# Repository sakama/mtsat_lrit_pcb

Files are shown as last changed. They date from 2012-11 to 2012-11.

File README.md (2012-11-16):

# MTSAT LRIT PCB

#What's this?#

----------
MTSATのLRIT信号を受信するためのダウンコンバータ及びデコーダの回路図。Eagleで作成。

[Maker Faire Tokyo 2012](http://makezine.jp/)に出品予定。

こちらの記事に書いてあるものを基板に起こしたもの
[http://www.wa.commufa.jp/gigast/SAT/LRIT/LRIT.html](http://www.wa.commufa.jp/gigast/SAT/LRIT/LRIT.html)

# How to use #

----------

Please download CadSoft [EAGLE PCB](http://www.cadsoftusa.com/)

# About MTSAT LRIT #

http://www.jma.go.jp/jma/jma-eng/satellite/mtsat1r/4.3LRIT.pdf

## License ##

----------

Non-Commecial Use Only

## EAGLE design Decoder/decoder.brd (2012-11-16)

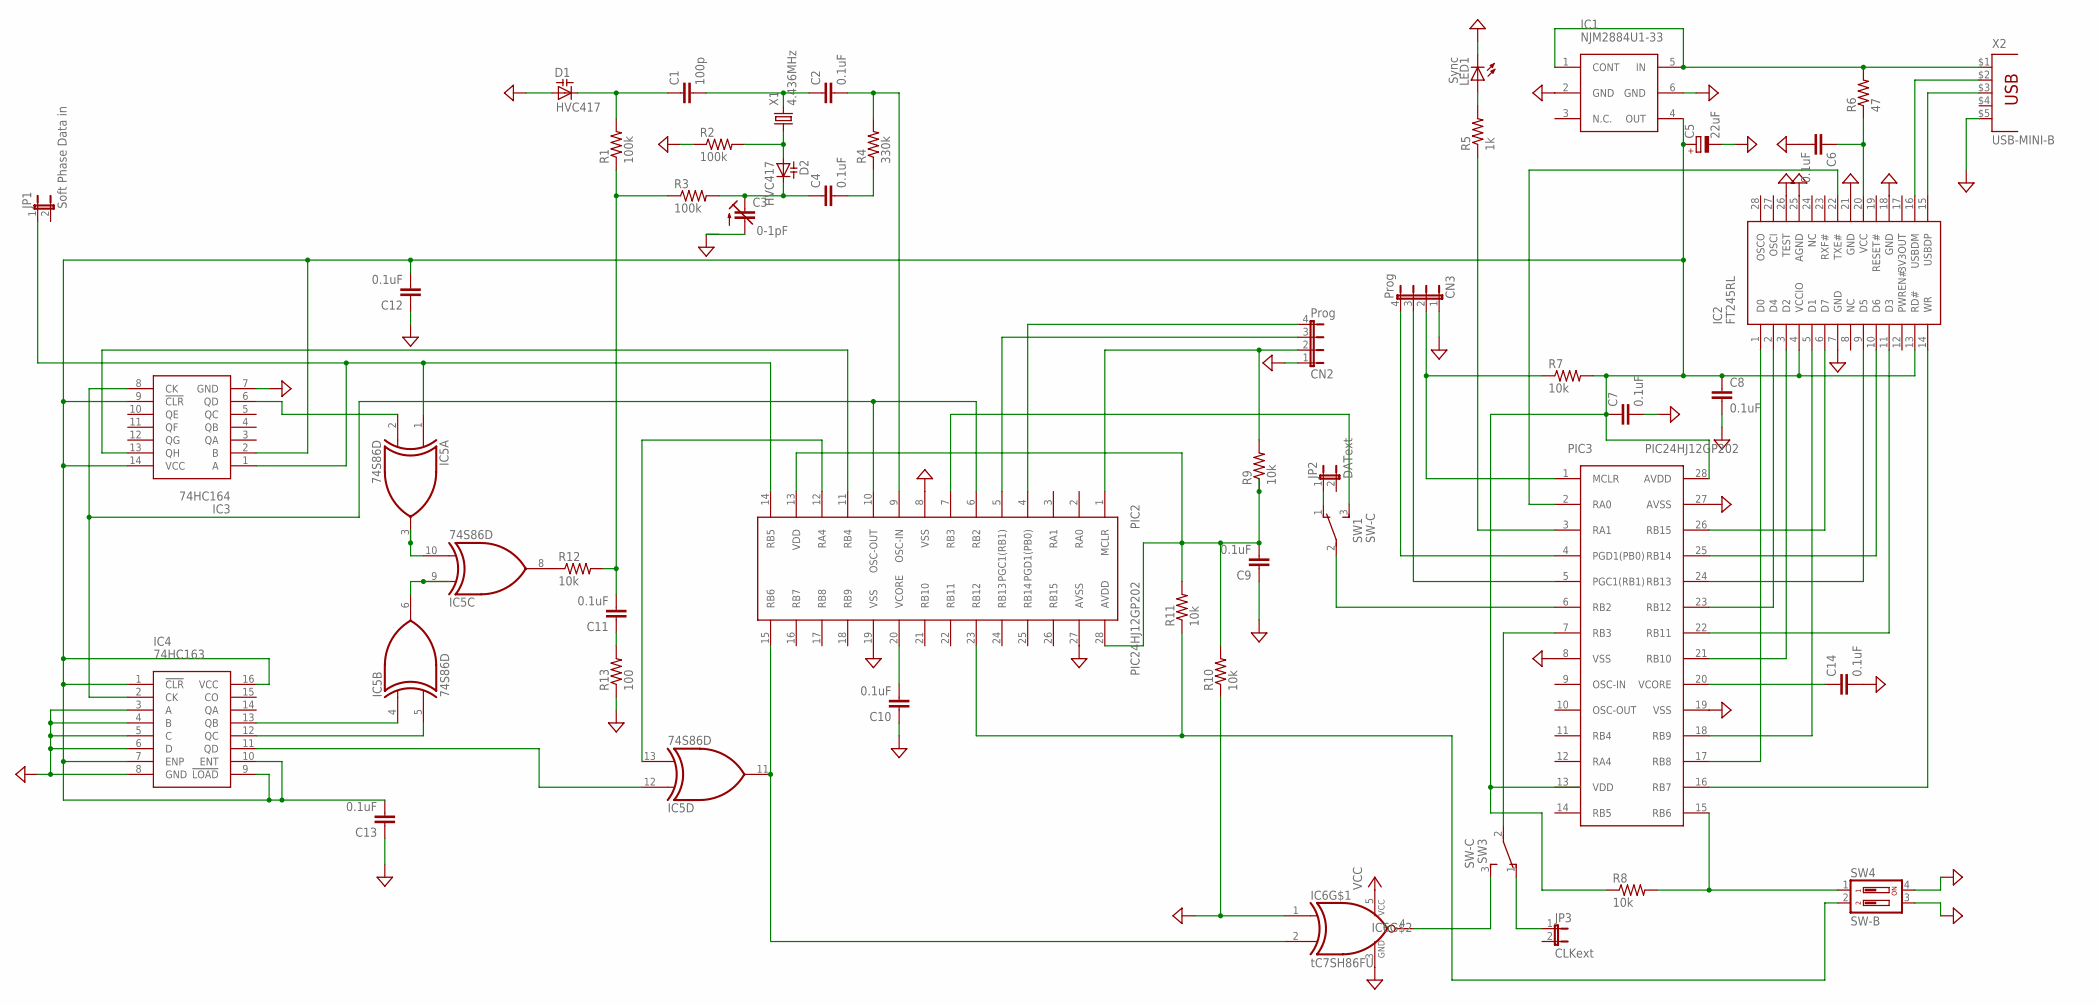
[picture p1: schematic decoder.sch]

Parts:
C1: 100p; C025-025X050
C2, C4, C6, C7, C8, C9, C10, C11, C12, C13, C14: 0.1uF; C050-025X075
C3: 0-1pF; CTRIMTZ03
C5: 22uF; E3,5-8
CN2, CN3: Prog; JP4
D1, D2: HVC417; SOT54H
IC1: NJM2884U1-33
IC2: FT245RL
IC3: 74HC164
IC4: 74HC163
IC5: 74S86D; SO14
IC6: tC7SH86FU; TC7SH86FU
JP1: Soft Phase Data in; JP1
JP2: DAText; JP1
JP3: CLKext; JP1
LED1: Sync; LED5MM
PIC2, PIC3: PIC24HJ12GP202
R1, R2, R3: 100k; 0207/7
R4: 330k; 0207/7
R5: 1k; 0207/7
R6: 47; 0207/7
R7, R8, R9, R10, R11, R12: 10k; 0207/7
R13: 100; 0207/7
SW1, SW3: SW-C; TL3XPO
SW4: SW-B; DIP02YL
X1: 4.436MHz; HC49/S
X2: USB-MINI-B

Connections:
GND: C3.2 (A), C5.-, C6.2, C7.2, C8.2, C9.1, C10.1, C12.1, C13.1, C14.2, CN2.1, CN3.1, D1.A, IC1.2 (GND), IC1.6 (GND), IC2.7 (GND), IC2.18 (GND), IC2.21 (GND), IC2.25 (AGND), IC2.26 (TEST), IC3.7 (GND), IC4.3 (A), IC4.4 (B), IC4.5 (C), IC4.6 (D), IC4.8 (GND), IC5.7 (GND), IC6.1 (I0), IC6.3 (GND), LED1.K (C), PIC2.8 (VSS), PIC2.19 (VSS), PIC2.27 (AVSS), PIC3.8 (VSS), PIC3.19 (VSS), PIC3.27 (AVSS), R2.1, R10.1, R13.1, SW4.3, SW4.4, X2.$5 (5)
unnamed: IC1.1 (CONT), IC1.5 (IN), R6.2, X2.$1 (1)
unnamed: C4.2, R4.1
unnamed: C1.2, C2.1, X1.2
unnamed: C2.2, PIC2.9 (OSC-IN), R4.2
unnamed: CN2.2, PIC2.1 (MCLR), R9.2
unnamed: C3.1 (E), C4.1, D2.C, R3.2
unnamed: C1.1, D1.C, R1.2
unnamed: IC5.8 (O), R12.1
unnamed: C10.2, PIC2.20 (VCORE)
unnamed: PIC2.23 (RB12), R11.1, SW4.2
unnamed: PIC3.15 (RB6), R8.2, SW4.1
unnamed: C11.1, R13.2
unnamed: PIC2.7 (RB3), SW1.3 (S)
unnamed: PIC3.6 (RB2), SW1.2
unnamed: IC5.11 (O), IC6.2 (I1), PIC2.15 (RB6)
unnamed: PIC3.3 (RA1), R5.1
unnamed: PIC3.7 (RB3), SW3.2
unnamed: C9.2, PIC2.13 (VDD), PIC2.28 (AVDD), R9.1, R10.2, R11.2
unnamed: IC2.22 (TXE#), PIC3.2 (RA0)
unnamed: C11.2, R1.1, R3.1, R12.2
unnamed: IC5.6 (O), IC5.9 (I0)
unnamed: IC5.3 (O), IC5.10 (I1)
unnamed: IC3.1 (A), IC5.1 (I0), JP1.1, PIC2.14 (RB5)
unnamed: IC5.13 (I1), PIC2.12 (RA4)
unnamed: IC2.14 (WR), PIC3.16 (RB7)
unnamed: D2.A, R2.2, X1.1
unnamed: IC2.10 (D6), PIC3.25 (RB14)
unnamed: IC2.15 (USBDP), X2.$3 (3)
unnamed: IC2.16 (USBDM), X2.$2 (2)
unnamed: IC2.11 (D3), PIC3.22 (RB11)
unnamed: IC2.9 (D5), PIC3.24 (RB13)
unnamed: IC2.1 (D0), PIC3.17 (RB8)
unnamed: IC2.2 (D4), PIC3.23 (RB12)
unnamed: IC2.3 (D2), PIC3.21 (RB10)
unnamed: IC2.5 (D1), PIC3.18 (RB9)
unnamed: IC2.6 (D7), PIC3.26 (RB15)
unnamed: IC3.6 (QD), IC5.2 (I1)
unnamed: IC3.13 (QH), PIC2.11 (RB4)
unnamed: IC4.13 (QB), IC5.4 (I0)
unnamed: IC4.12 (QC), IC5.5 (I1)
unnamed: IC4.11 (QD), IC5.12 (I0)
unnamed: JP3.1, SW3.1 (O)
unnamed: C5.+, C7.1, C8.1, C12.2, C13.2, IC1.4 (OUT), IC2.4 (VCCIO), IC2.13 (RD#), IC3.2 (B), IC3.9 (!CLR), IC3.14 (VCC), IC4.1 (!CLR), IC4.7 (ENP), IC4.9 (!LOAD), IC4.10 (ENT), IC4.16 (VCC), PIC3.28 (AVDD), R7.2, R8.1
unnamed: IC3.8 (CK), IC4.2 (CK), PIC2.6 (RB2), PIC2.10 (OSC-OUT)
unnamed: C6.1, IC2.20 (VCC), R6.1
unnamed: CN2.3, PIC2.5 (PGC1(RB1))
unnamed: CN2.4, PIC2.4 (PGD1(PB0))
unnamed: CN3.2, PIC3.1 (MCLR), R7.1
unnamed: CN3.3, PIC3.5 (PGC1(RB1))
unnamed: CN3.4, PIC3.4 (PGD1(PB0))
unnamed: LED1.A, R5.2
unnamed: JP2.1, SW1.1 (O)
unnamed: IC6.4 (O), SW3.3 (S)
unnamed: C14.1, PIC3.20 (VCORE)
VCC: IC5.14 (VCC), IC6.5 (VCC)
VDD: PIC3.13 (VDD)

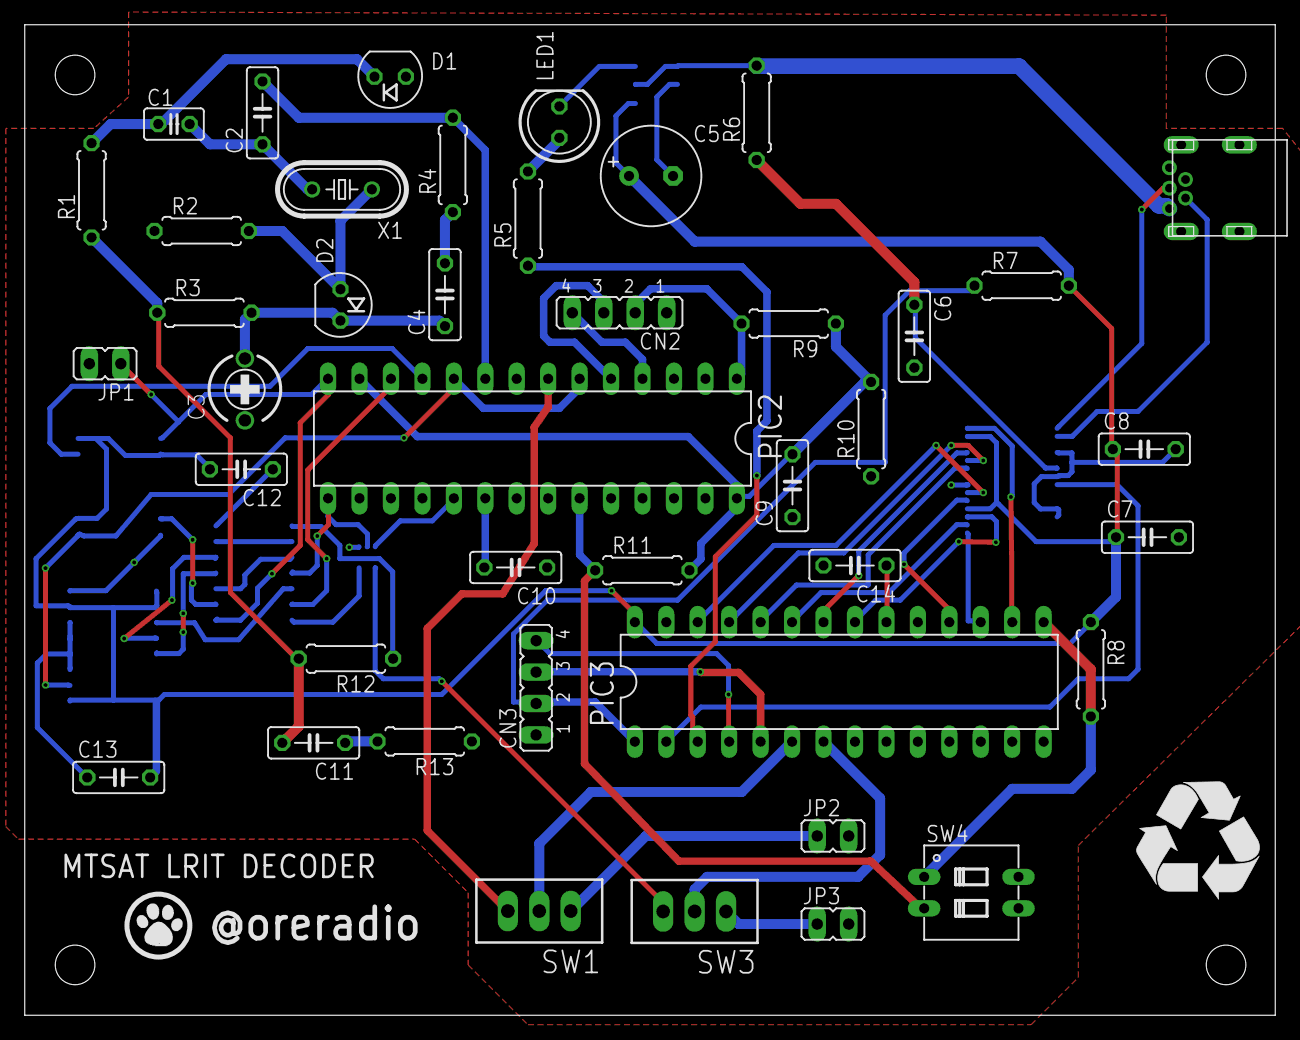
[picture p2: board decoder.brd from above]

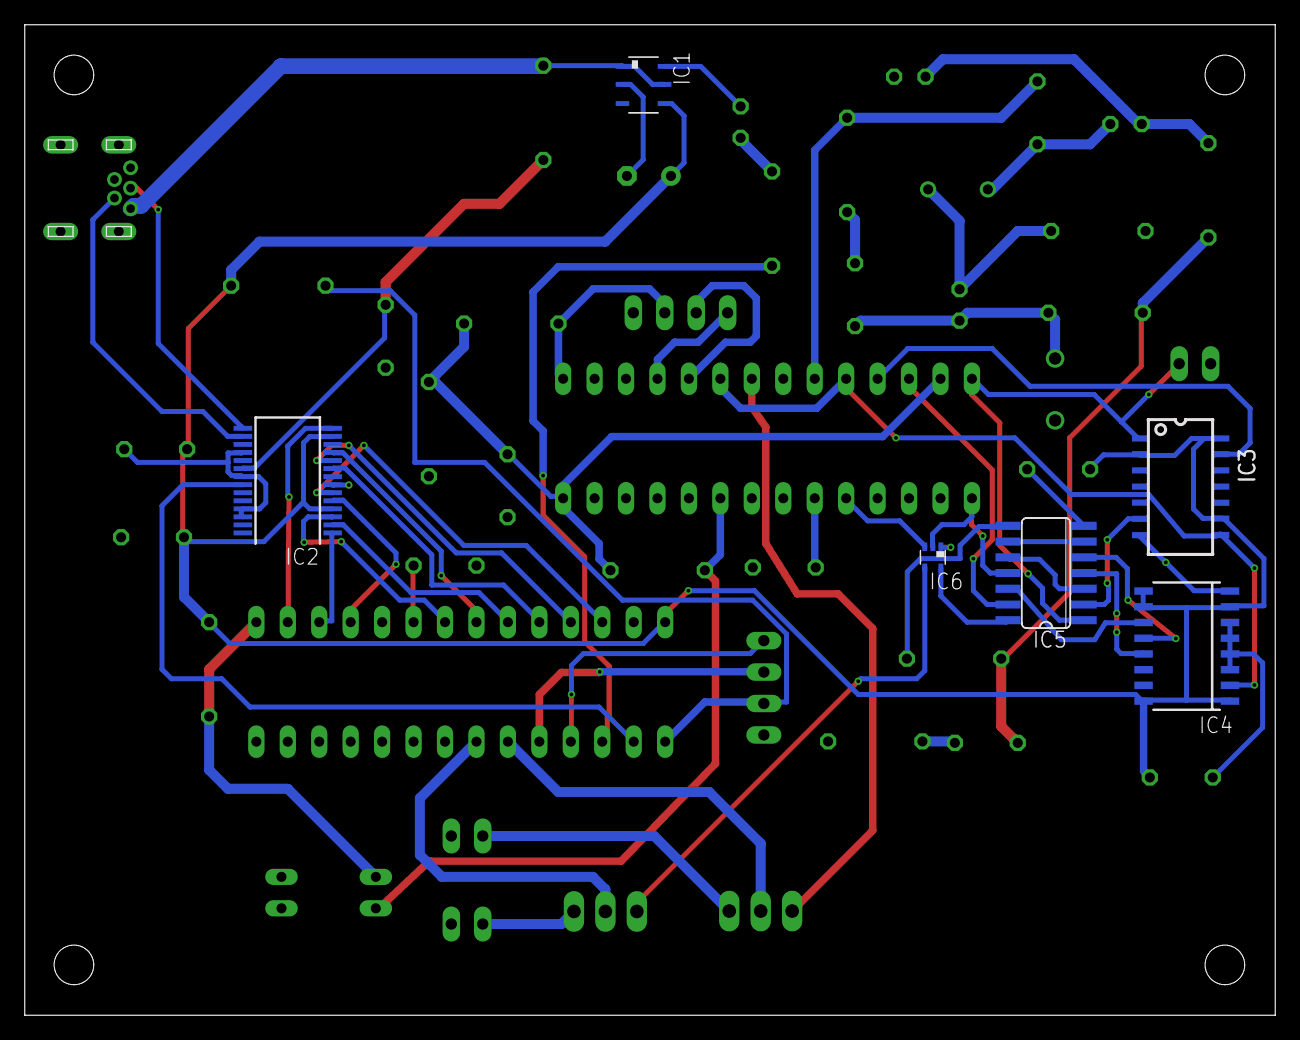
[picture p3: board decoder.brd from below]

Board: 2 copper layers, 101.0 x 80.0 mm, 50 parts (6 on the bottom side), 56 nets.

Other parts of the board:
U$36: LOGO
U$38: RECYCLING_10.00

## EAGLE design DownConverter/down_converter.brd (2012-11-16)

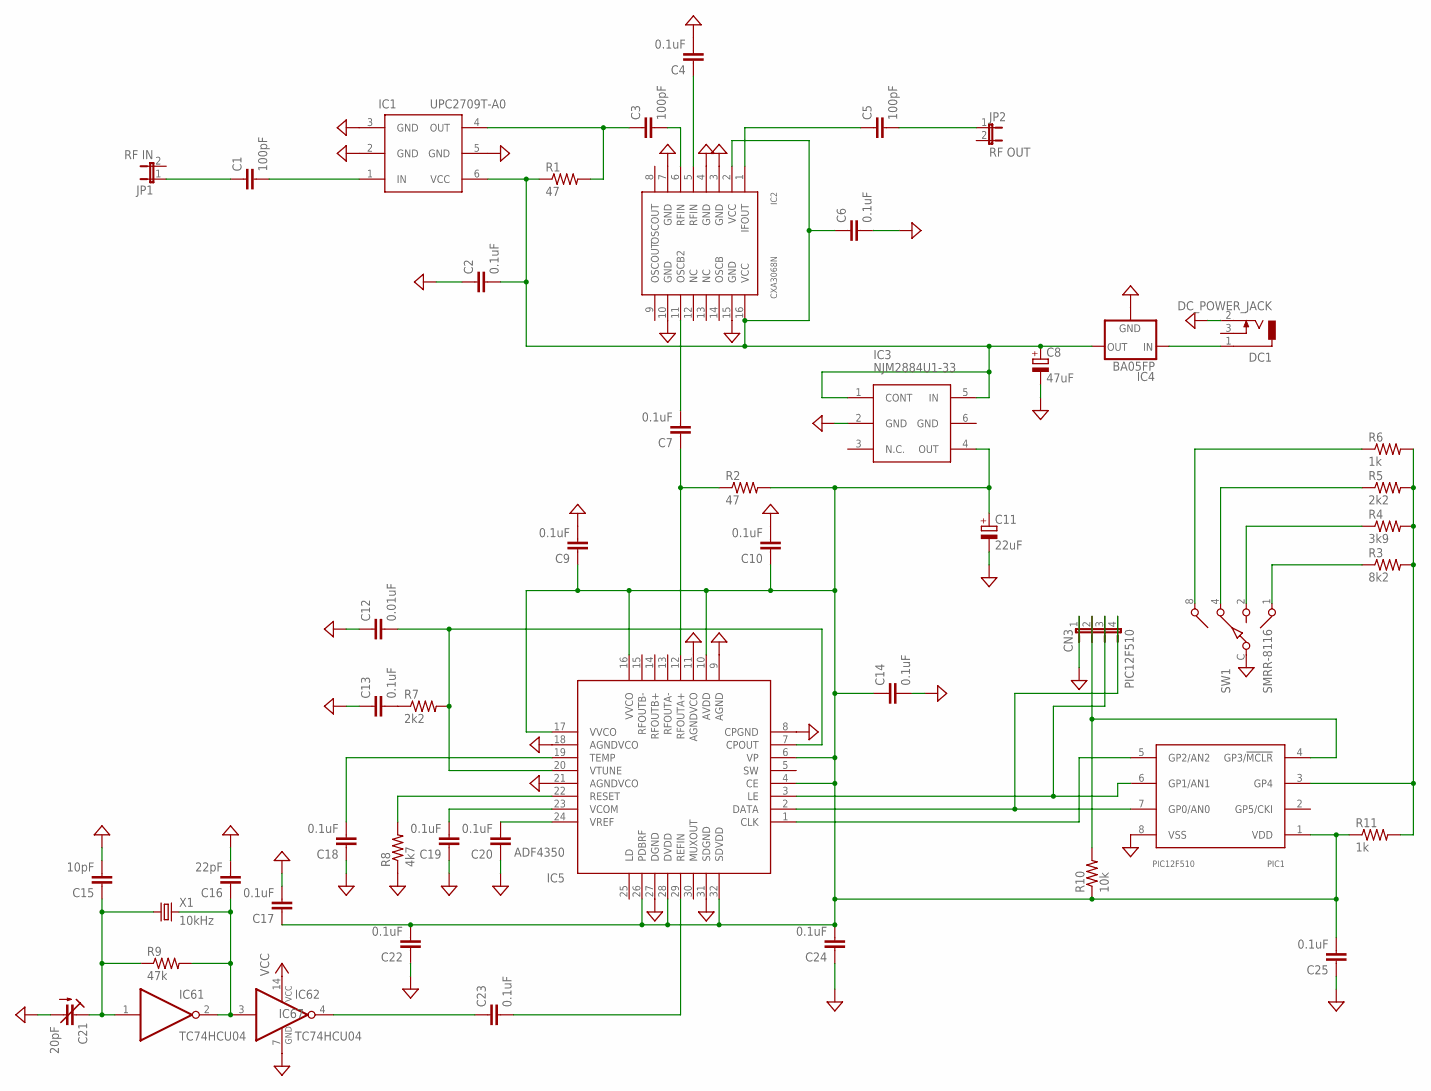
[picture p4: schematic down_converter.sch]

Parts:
C1, C3, C5: 100pF; C025-025X050
C2, C4, C6, C7, C9, C10, C13, C14, C17, C18, C19, C20, C22, C23, C24, C25: 0.1uF; C050-025X075
C8: 47uF; E5-10,5
C11: 22uF; E3,5-8
C12: 0.01uF; C025-025X050
C15: 10pF; C025-025X050
C16: 22pF; C025-025X050
C21: 20pF; CTRIMTZ03
CN3: PIC12F510; JP4
DC1: DC_POWER_JACK
IC1: UPC2709T-A0; SOT23-6
IC2: CXA3068N
IC3: NJM2884U1-33
IC4: BA05FP
IC5: ADF4350
IC6: TC74HCU04
JP1: RF IN; JP1
JP2: RF OUT; JP1
PIC1: PIC12F510; PIC12F1288
R1, R2: 47; 0207/7
R3: 8k2; 0207/7
R4: 3k9; 0207/7
R5, R7: 2k2; 0207/7
R6, R11: 1k; 0207/7
R8: 4k7; 0207/7
R9: 47k; 0207/7
R10: 10k; 0207/7
SW1: SMRR-8116; SW-C16
X1: 10kHz; HC49/S

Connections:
GND: C2.1, C4.2, C6.2, C8.-, C9.2, C10.2, C11.-, C12.1, C13.1, C14.2, C15.2, C16.2, C17.2, C18.1, C19.1, C20.1, C21.2 (A), C22.1, C24.1, C25.1, CN3.1, DC1.2, IC1.2 (GND), IC1.3 (GND), IC1.5 (GND), IC2.3 (GND), IC2.4 (GND), IC2.7 (GND), IC2.10 (GND), IC2.15 (GND), IC3.2 (GND), IC3.6 (GND), IC4.2 (GND), IC5.8 (CPGND), IC5.9 (AGND), IC5.11 (AGNDVCO), IC5.18 (AGNDVCO), IC5.21 (AGNDVCO), IC5.27 (DGND), IC5.31 (SDGND), IC6.7 (GND), PIC1.8 (VSS), R8.1, SW1.C
unnamed: C13.2, R7.1
unnamed: DC1.1, IC4.1 (IN)
unnamed: C23.2, IC5.29 (REFIN)
unnamed: C20.2, IC5.24 (VREF)
unnamed: C19.2, IC5.23 (VCOM)
unnamed: IC5.22 (RESET), R8.2
unnamed: C18.2, IC5.19 (TEMP)
unnamed: C12.2, IC5.7 (CPOUT), IC5.20 (VTUNE), R7.2
unnamed: C7.1, IC5.12 (RFOUTA+), R2.1
unnamed: C2.2, C6.1, C8.+, IC1.6 (VCC), IC2.2 (VCC), IC2.16 (VCC), IC3.1 (CONT), IC3.5 (IN), IC4.3 (OUT), R1.1
unnamed: IC5.1 (CLK), PIC1.5 (GP2/AN2)
unnamed: PIC1.3 (GP4), R3.2, R4.2, R5.2, R6.2, R11.2
unnamed: C7.2, IC2.11 (OSCB2)
unnamed: C3.1, IC1.4 (OUT), R1.2
unnamed: C1.2, IC1.1 (IN)
unnamed: C3.2, IC2.6 (RFIN)
unnamed: C4.1, IC2.5 (RFIN)
unnamed: C5.1, IC2.1 (IFOUT)
unnamed: R6.1, SW1.8
unnamed: CN3.2, PIC1.4 (GP3/!MCLR), R10.2
unnamed: R5.1, SW1.4
unnamed: R4.1, SW1.2
unnamed: R3.1, SW1.1
unnamed: CN3.3, IC5.3 (LE), PIC1.6 (GP1/AN1)
unnamed: C5.2, JP2.1
unnamed: C1.1, JP1.1
unnamed: C9.1, C10.1, C11.+, C14.1, C17.1, C22.2, C24.2, C25.2, IC3.4 (OUT), IC5.4 (CE), IC5.6 (VP), IC5.10 (AVDD), IC5.16 (VVCO), IC5.17 (VVCO), IC5.26 (PDBRF), IC5.28 (DVDD), IC5.32 (SDVDD), PIC1.1 (VDD), R2.2, R10.1, R11.1
unnamed: C16.1, IC6.2 (Y), IC6.3 (A), R9.2, X1.2
unnamed: C15.1, C21.1 (E), IC6.1 (A), R9.1, X1.1
unnamed: C23.1, IC6.4 (Y)
unnamed: CN3.4, IC5.2 (DATA), PIC1.7 (GP0/AN0)
VCC: IC6.14 (VCC)

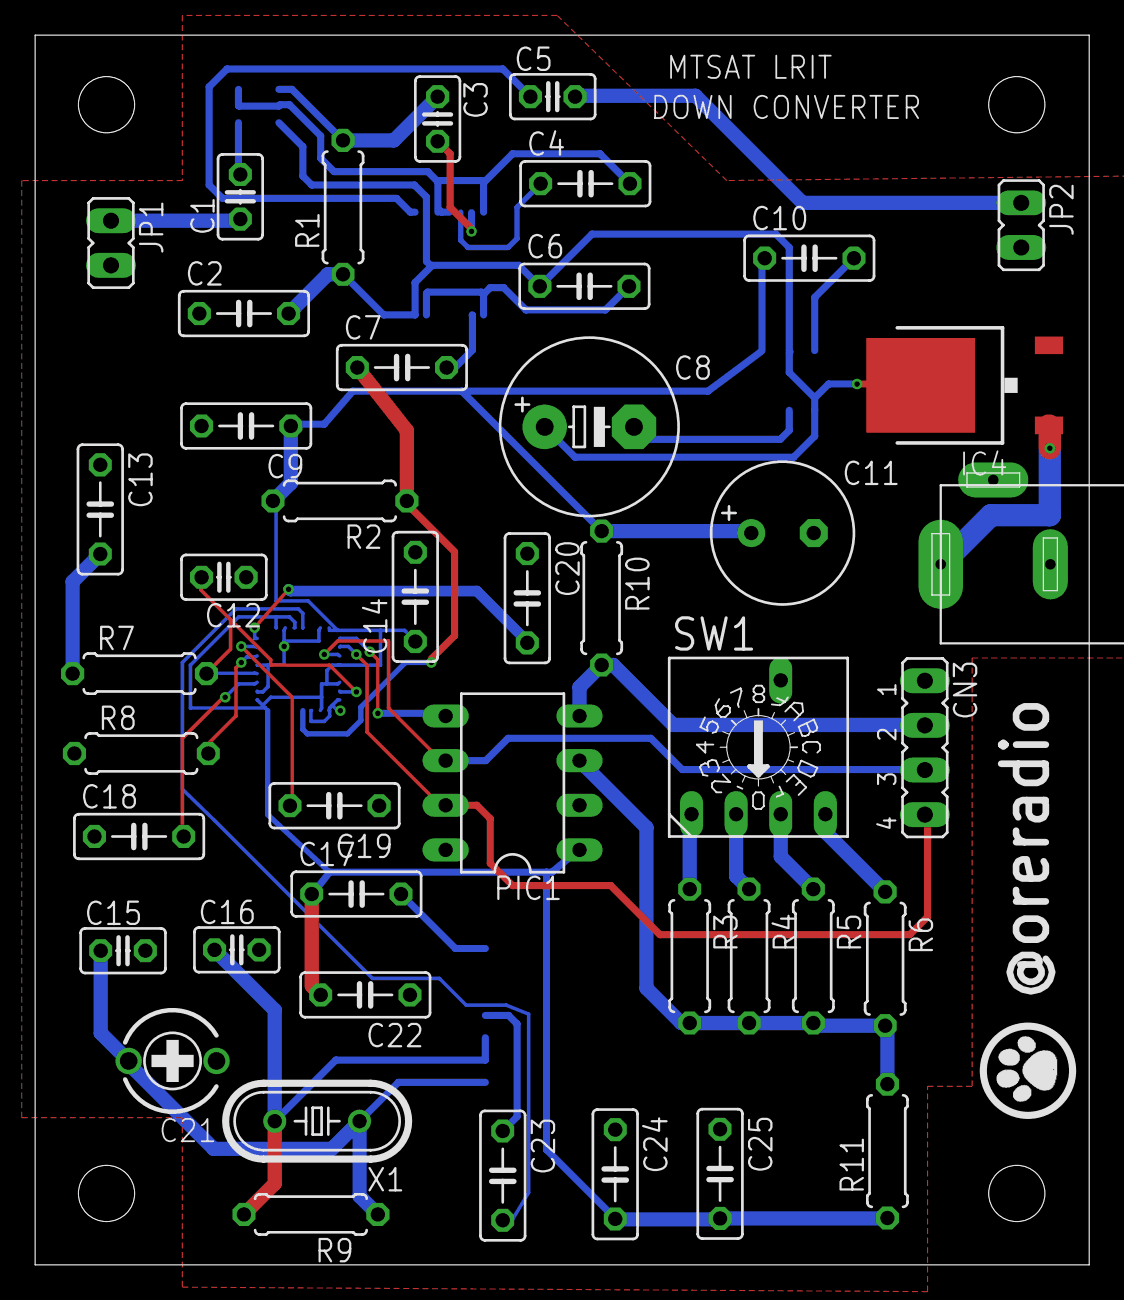
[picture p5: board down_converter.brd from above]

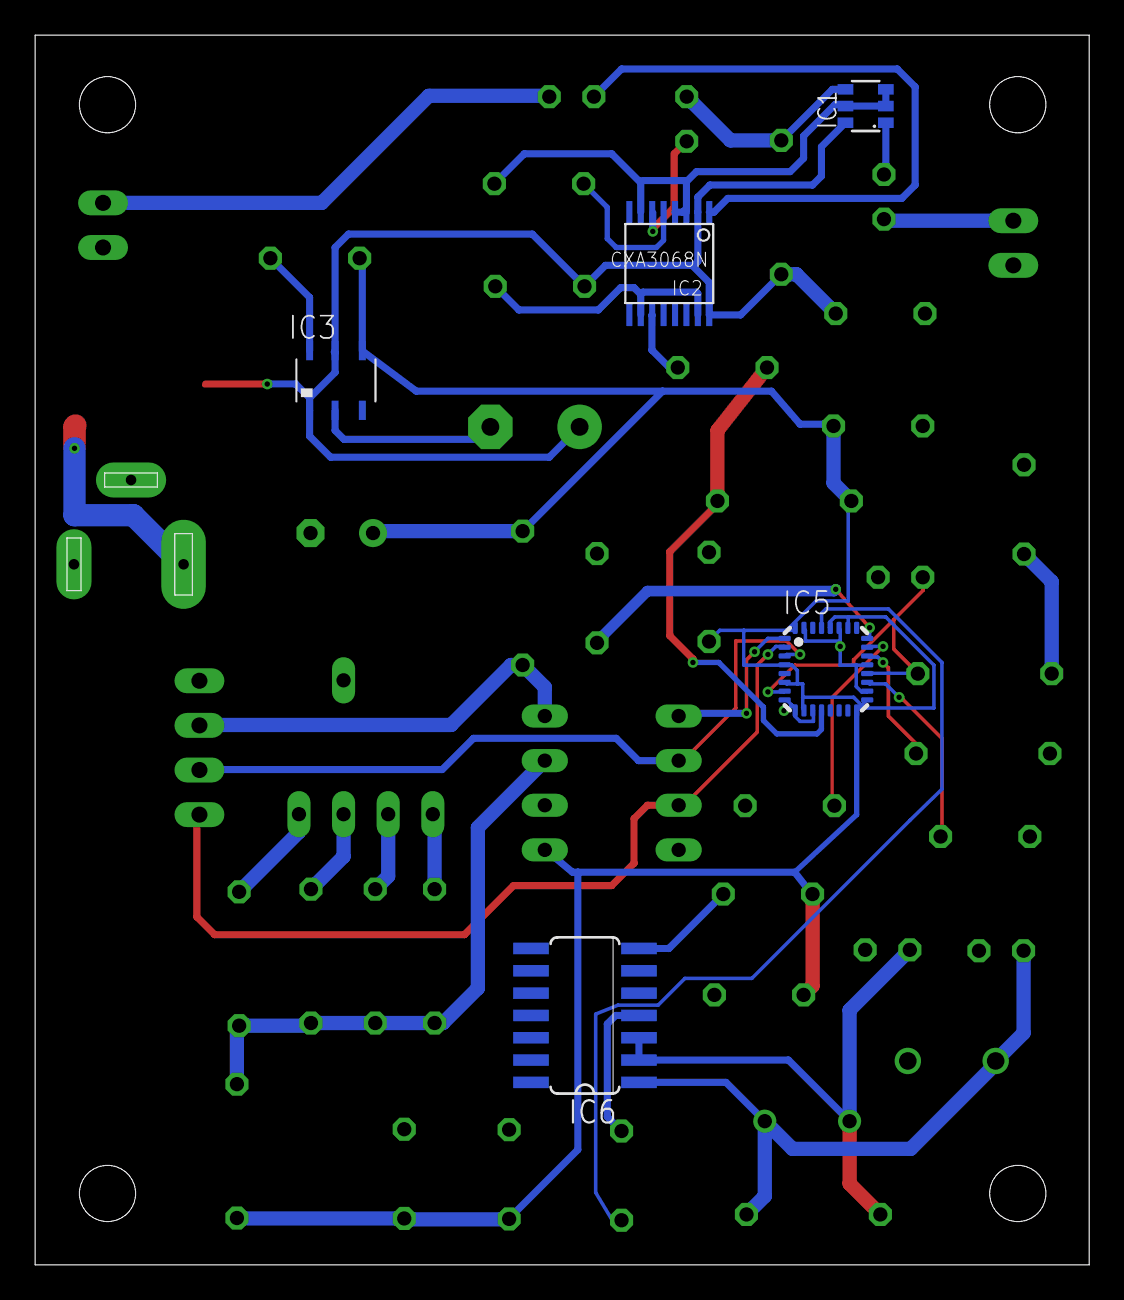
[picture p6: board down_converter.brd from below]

Board: 2 copper layers, 60.0 x 70.0 mm, 50 parts (5 on the bottom side), 32 nets.

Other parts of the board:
U$40: LOGO
